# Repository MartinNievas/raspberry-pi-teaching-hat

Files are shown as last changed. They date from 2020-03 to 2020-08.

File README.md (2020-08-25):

# raspberry-pi-teaching-hat

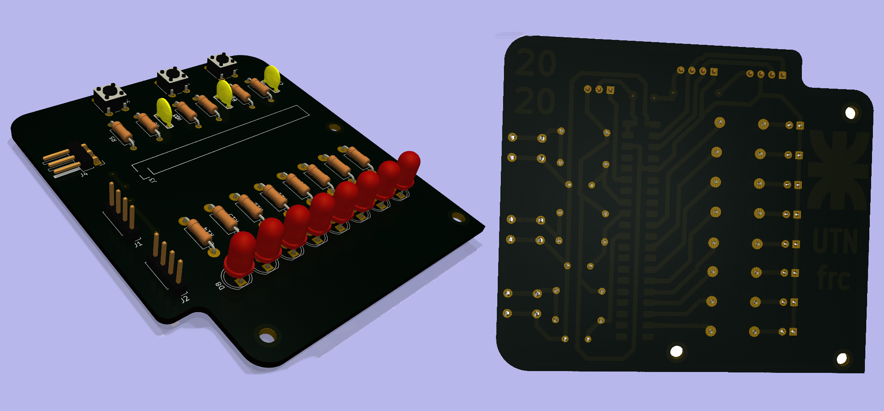
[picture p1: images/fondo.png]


## Pinout

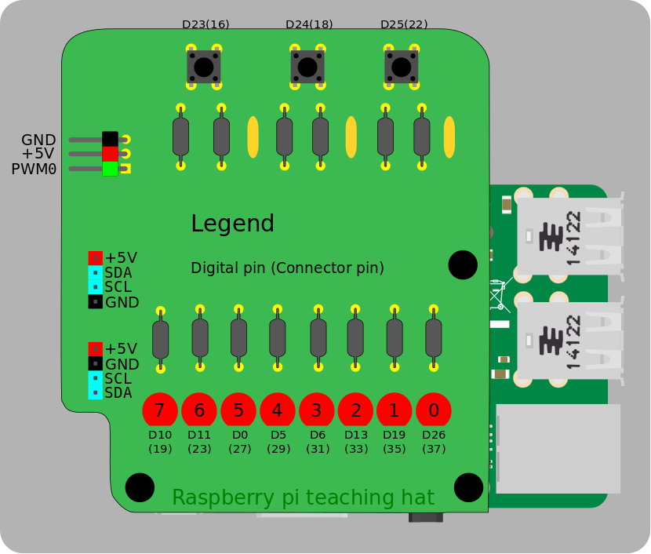
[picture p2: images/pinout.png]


## Programa de ejemplo
Un programa de ejemplo se encuentra en la carpeta lib/

Ejecutar:

```bash
gcc ejemplo.c && sudo ./a.out
```
Nota: sudo es necesario para acceder al pinout.

---
Para más información ir a la [Wiki](https://github.com/MartinNievas/raspberry-pi-teaching-hat/wiki)
---

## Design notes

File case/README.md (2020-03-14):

# Case

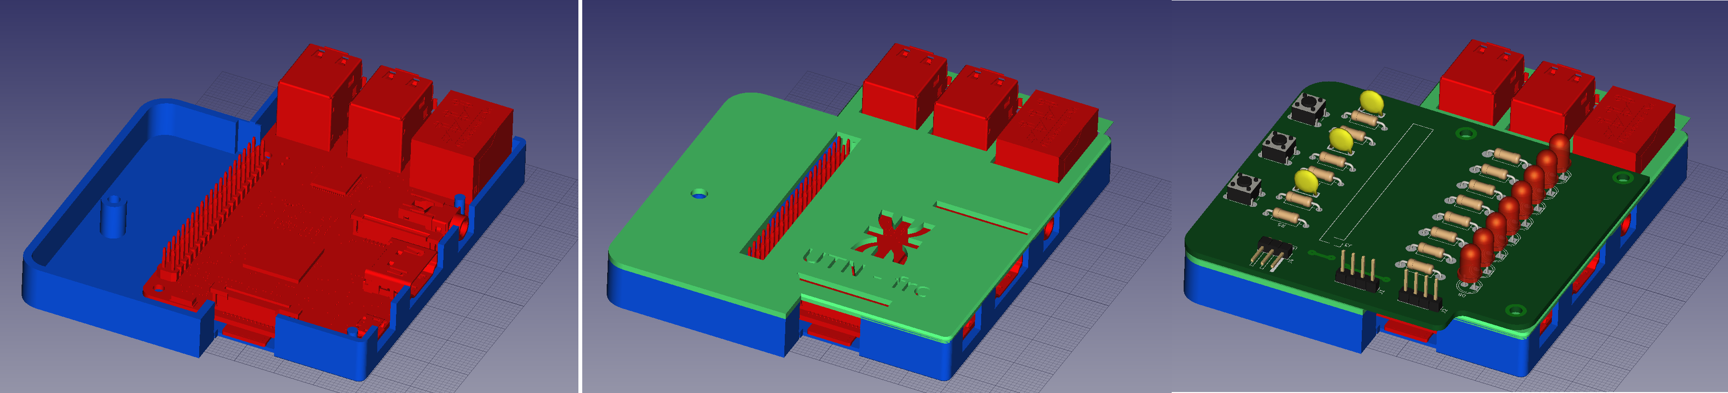
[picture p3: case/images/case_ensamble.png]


En este directorio se encuentra:
- archivos para imprimir en 3D (stl)
- el modelo de FreeCAD (V 0.18.4) para modificar.

### Modelos stl
Los modelos stl para descargar son:
- [base](stl/bottom.stl)
- [tapa](stl/top.stl)

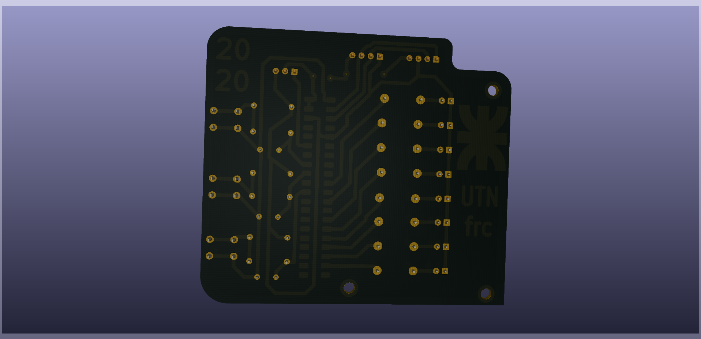
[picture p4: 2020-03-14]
images/atras.png

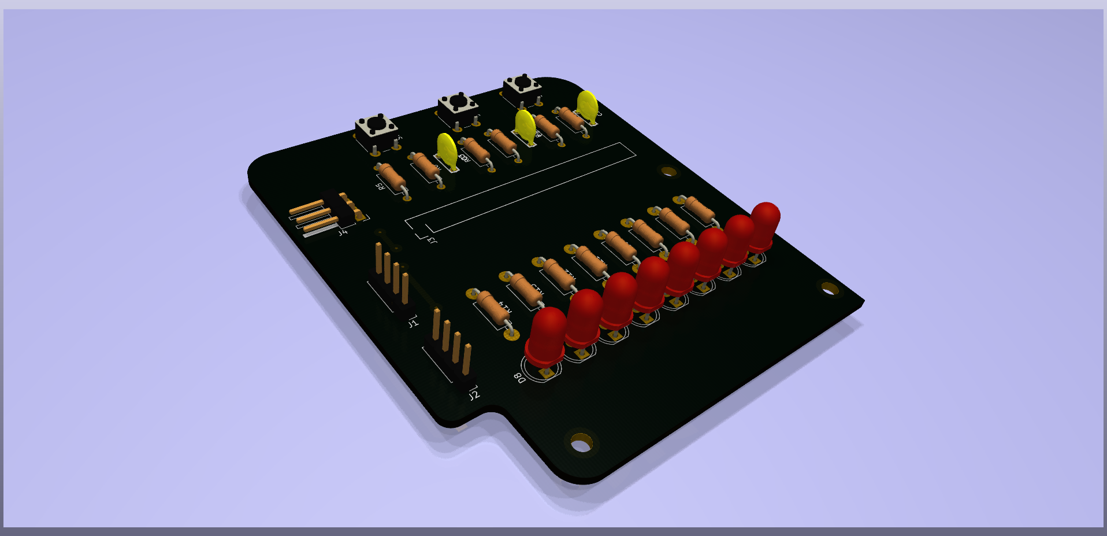
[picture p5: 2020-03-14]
images/adelante.png

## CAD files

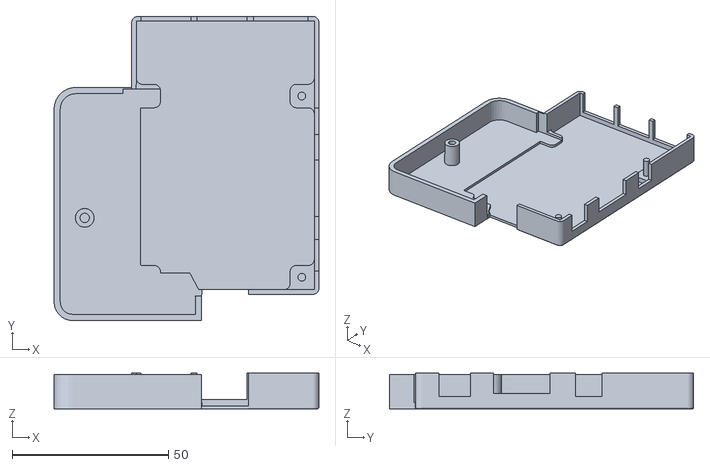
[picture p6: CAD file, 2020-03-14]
case/stl/bottom.stl
84.8 x 97.4 x 11.5

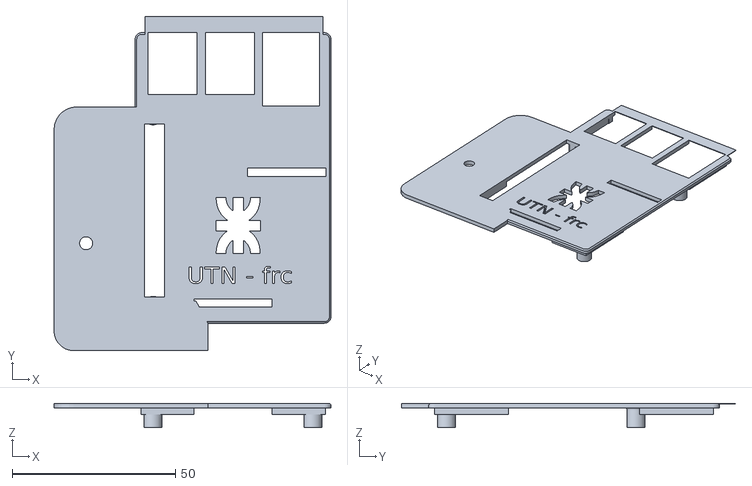
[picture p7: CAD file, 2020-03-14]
case/stl/top.stl
84.8 x 102.4 x 7.50

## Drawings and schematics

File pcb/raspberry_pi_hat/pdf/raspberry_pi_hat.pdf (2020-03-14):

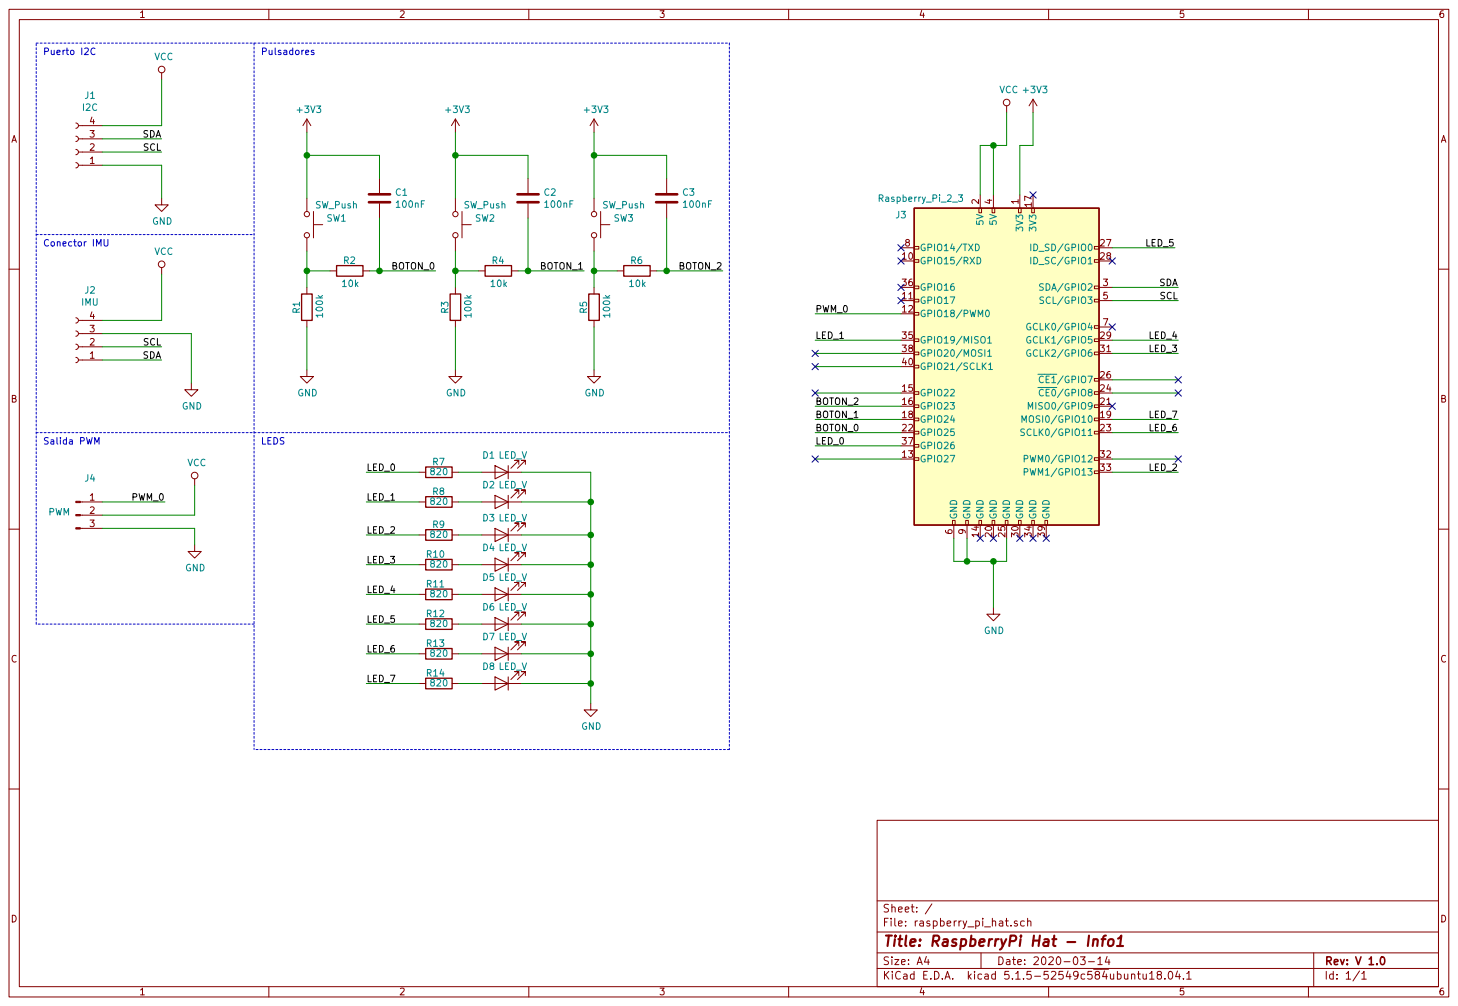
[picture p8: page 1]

Puerto I2C 3 SCL SDA 2 1

Conector IMU VCC 3

Salida PWM 3 | LEDS 820 D1 LED_V

File: raspberry_pi_hat.sch Sheet: /
Id: 1/1 Title: RaspberryPi Hat - Info1

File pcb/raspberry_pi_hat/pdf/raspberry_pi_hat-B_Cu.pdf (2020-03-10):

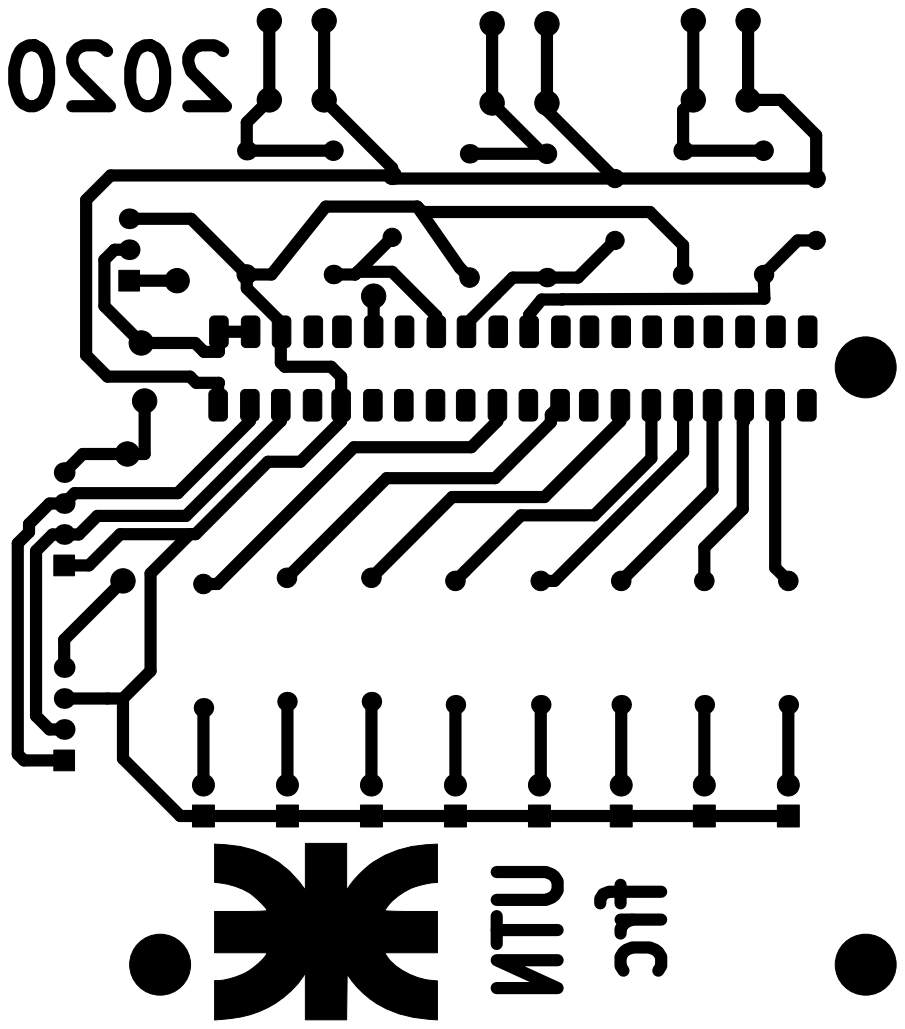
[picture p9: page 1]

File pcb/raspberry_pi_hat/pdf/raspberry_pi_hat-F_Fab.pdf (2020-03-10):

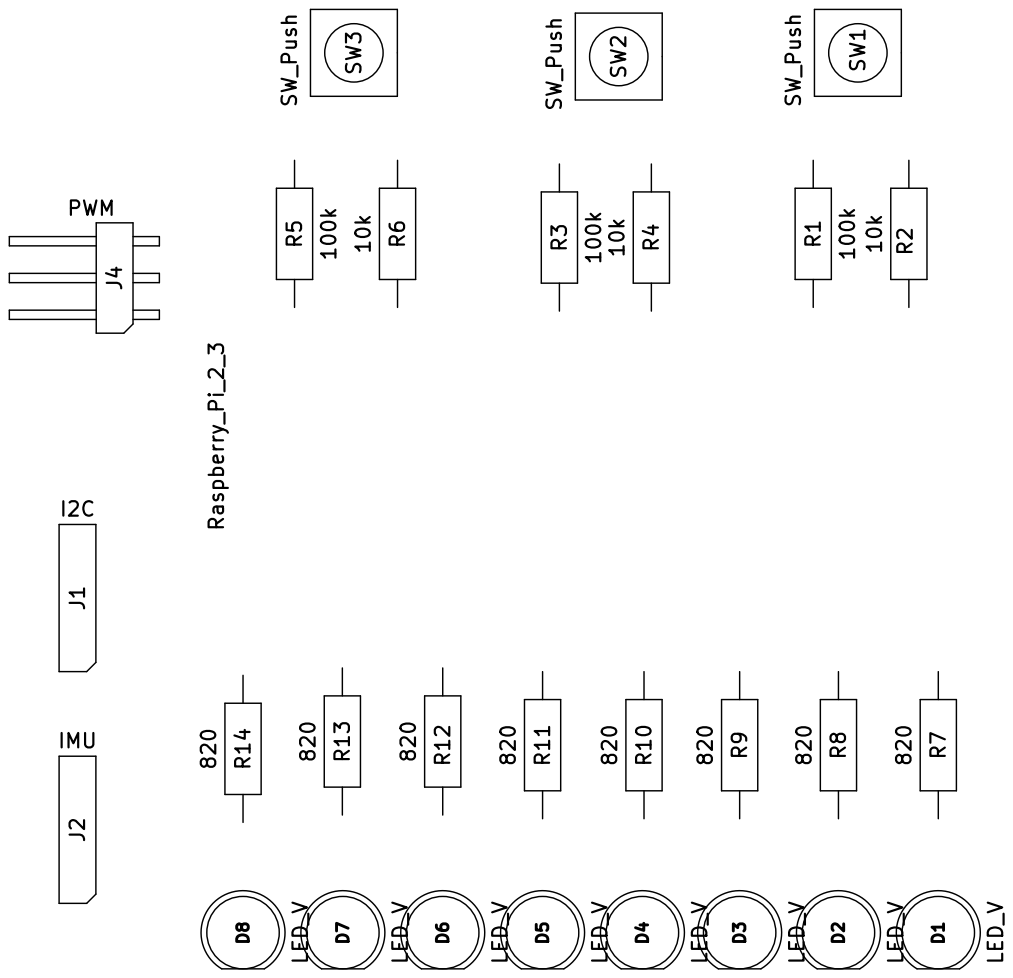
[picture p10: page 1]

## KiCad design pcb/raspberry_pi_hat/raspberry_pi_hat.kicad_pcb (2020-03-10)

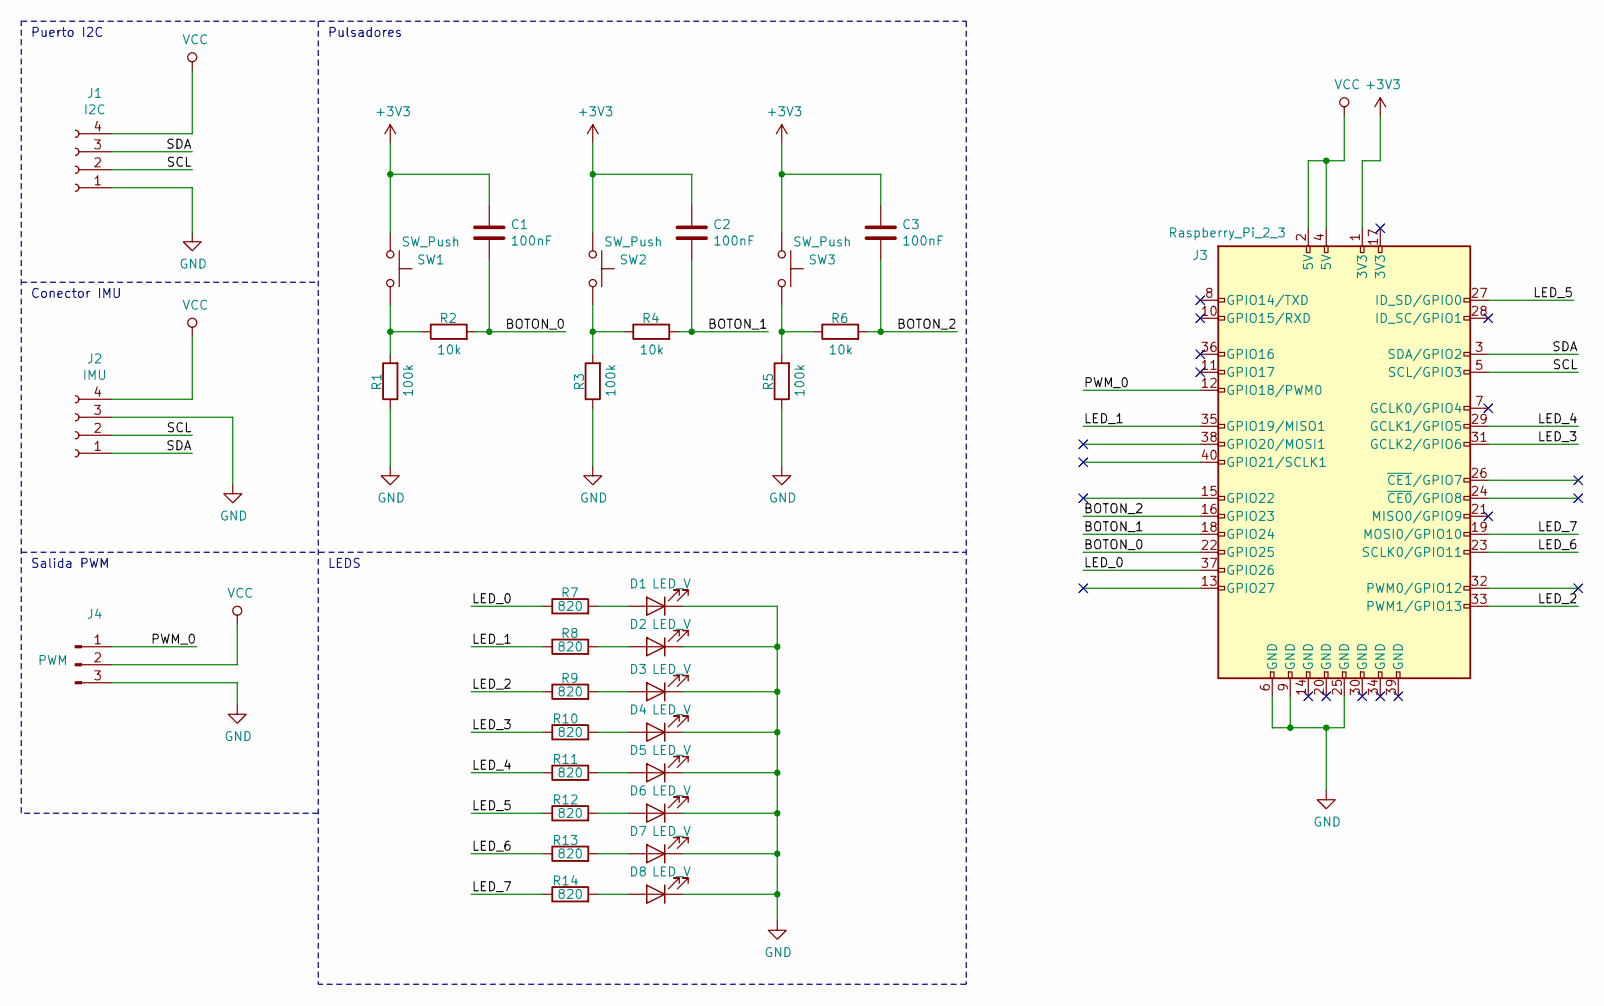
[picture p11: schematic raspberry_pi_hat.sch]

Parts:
C1, C2, C3: 100nF; cnp_6mm_disc
D1, D2, D3, D4, D5, D6, D7, D8: LED_V; LED_D5.0mm
J1: I2C; PinHeader_1x04_P2.54mm_Vertical
J2: IMU; PinHeader_1x04_P2.54mm_Vertical
J3: Raspberry_Pi_2_3; Pin_Header_Straight_2x20
J4: PWM; PinHeader_1x03_P2.54mm_Horizontal
R1, R3, R5: 100k; R_BIG_Axial_DIN0207
R2, R4, R6: 10k; R_BIG_Axial_DIN0207
R7, R8, R9, R10, R11, R12, R13, R14: 820; R_BIG_Axial_DIN0207
SW1, SW2, SW3: SW_Push; SW_PUSH_6mm

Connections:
+3V3: C1.1, C2.1, C3.1, J3.1 (3V3), SW1.1, SW2.1, SW3.1
/BOTON_0: C1.2, J3.22 (GPIO25), R2.2
/BOTON_1: C2.2, J3.18 (GPIO24), R4.2
/BOTON_2: C3.2, J3.16 (GPIO23), R6.2
/LED_0: J3.37 (GPIO26), R7.1
/LED_1: J3.35 (GPIO19/MISO1), R8.1
/LED_2: J3.33 (PWM1/GPIO13), R9.1
/LED_3: J3.31 (GCLK2/GPIO6), R10.1
/LED_4: J3.29 (GCLK1/GPIO5), R11.1
/LED_5: J3.27 (ID_SD/GPIO0), R12.1
/LED_6: J3.23 (SCLK0/GPIO11), R13.1
/LED_7: J3.19 (MOSI0/GPIO10), R14.1
/PWM_0: J3.12 (GPIO18/PWM0), J4.1
/SCL: J1.2, J2.2, J3.5 (SCL/GPIO3)
/SDA: J1.3, J2.1, J3.3 (SDA/GPIO2)
GND: D1.1 (K), D2.1 (K), D3.1 (K), D4.1 (K), D5.1 (K), D6.1 (K), D7.1 (K), D8.1 (K), J1.1, J2.3, J3.6 (GND), J3.9 (GND), J3.25 (GND), J4.3, R1.1, R3.1, R5.1
unnamed: D1.2 (A), R7.2
unnamed: D2.2 (A), R8.2
unnamed: D3.2 (A), R9.2
unnamed: D4.2 (A), R10.2
unnamed: D5.2 (A), R11.2
unnamed: D6.2 (A), R12.2
unnamed: D7.2 (A), R13.2
unnamed: D8.2 (A), R14.2
unnamed: R1.2, R2.1, SW1.2
unnamed: R3.2, R4.1, SW2.2
unnamed: R5.2, R6.1, SW3.2
VCC: J1.4, J2.4, J3.2 (5V), J3.4 (5V), J4.2

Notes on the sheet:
Puerto I2C
Conector IMU
Salida PWM
LEDS
Pulsadores

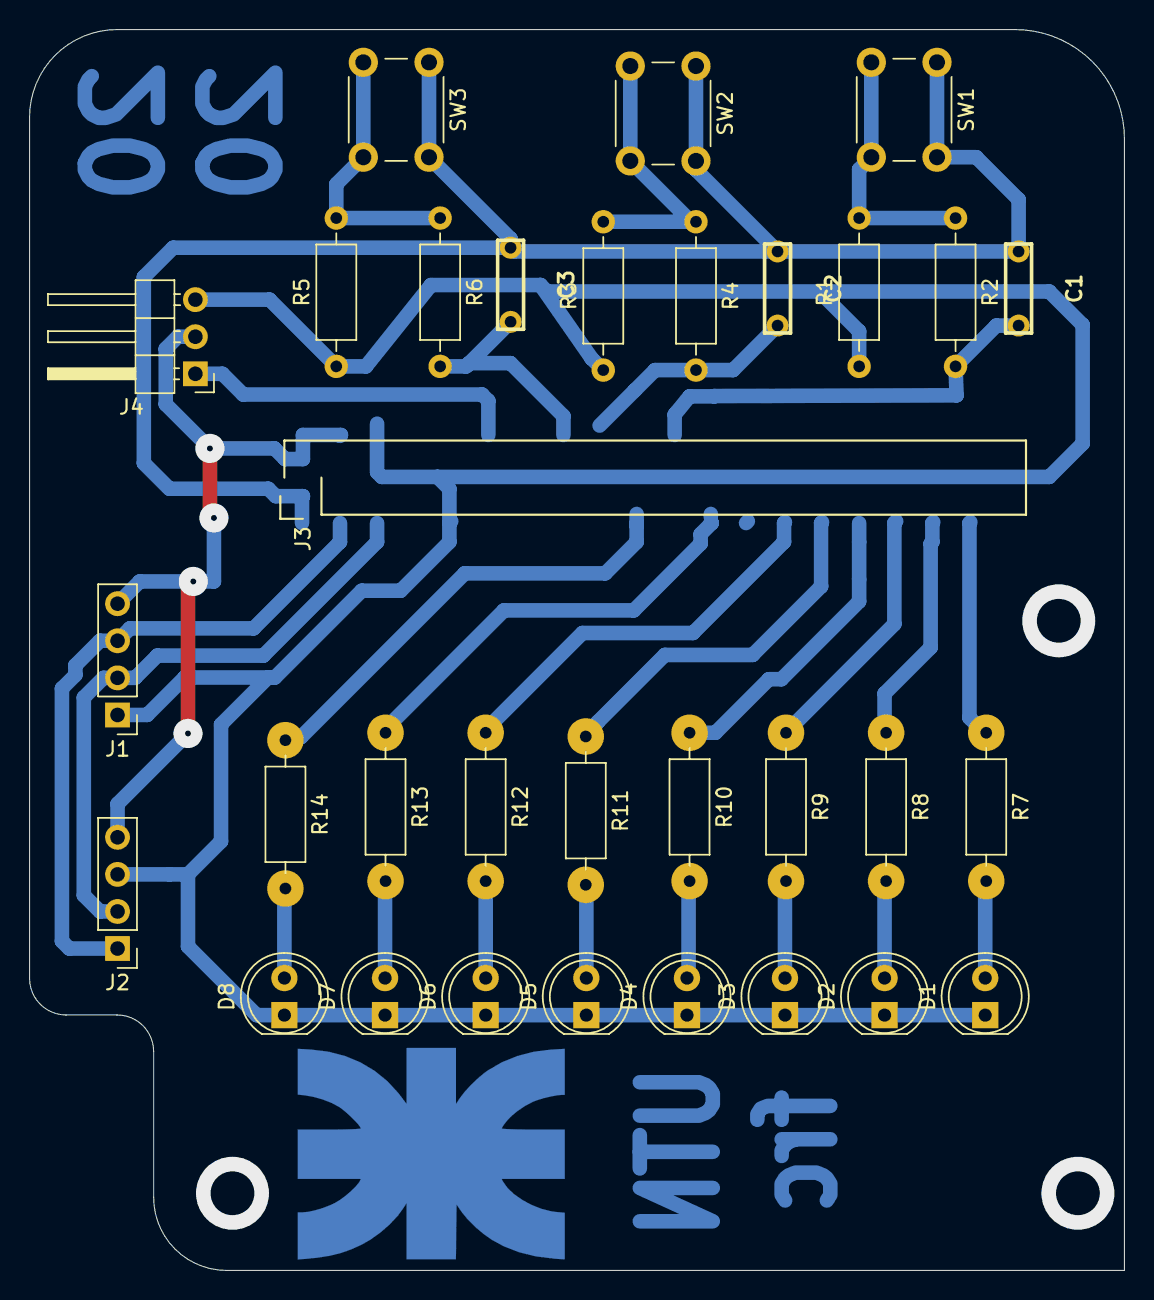
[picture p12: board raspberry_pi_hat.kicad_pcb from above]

Board: 2 copper layers, 75.0 x 85.0 mm, 32 parts (0 on the bottom side), 28 nets.

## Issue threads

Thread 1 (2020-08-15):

Pasar de MAkefile a CMakeFile

MartinNievas, 2020-08-15:
La idea es lo del título. En la carpeta /lib está el archivo, se podría renombrar /lib a /code y crear los ejemplos dentro. Lo dejo abierto para que alguien pueda tomarlo

- [ ] Renombrar la carpeta /lib a /code
- [ ] Crear el archivo CMakeLists.txt con las dependencias necesarias para compilar el código y biblioteca
- [ ] Mover el código a /code/src y las bibliotecas estáticas a /code/lib

MartinNievas, 2020-08-25:
Cuando se renombren los directorios, hay que actualizar la wiki también

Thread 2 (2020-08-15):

Migrar la documentación a la wiki del repo

MartinNievas, 2020-08-15:
La documentación de la placa actual, originalmente estaba en el [blog](https://martinnievas.com/myblog/2020-03-15-raspberrypi-teaching-hat/).
La [versión anterior](https://martinnievas.com/myblog/2019-10-09-placa-raspberry-pi/) (que eran un montón de fotos) quedará por cuestiones históricas, pero habría que mencionarla en la wiki para tener una referencia de porqué se usaron esos piners.

MartinNievas, 2020-08-25:
Migrada!
Faltaría gente para no transformar esto en un largo y aburrido monólogo (*pst* vos que estás leyendo esto, los PR son bienvenidos)

MartinNievas, 2020-08-25:
[La wiki](https://github.com/MartinNievas/raspberry-pi-teaching-hat/wiki) is Up!

Closed 2020-10-14.

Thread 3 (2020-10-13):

Agregar sugerencia de correr con sudo cuando no se puede abrir el archivo

MartinNievas, 2020-10-13:
El programa debe ser ejecutado con `sudo` para poder acceder a `/dev/mem`, de lo contrario muestra un error:

```bash
can't open /dev/mem
```
Que puede no llegar a ser claro su origen

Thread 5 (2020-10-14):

Faltan los links al esquemático en la wiki

MartinNievas, 2020-10-14:
El [link](https://github.com/MartinNievas/raspberry-pi-teaching-hat/blob/master/pcb/raspberry_pi_hat/pdf/raspberry_pi_hat.pdf)  al esquemático no está en la wiki, podría ser de utilidad.

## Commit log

2019-07-02 Add gitignore for KiCad files
2020-02-26 Agrega versión 0.1 del hat
    [raspberry_pi_hat.kicad_pcb, raspberry_pi_hat.sch]
2020-02-26 Agrega renders de la placa
2020-03-10 Agrega modificaciones en el tamaño del PCB
    [raspberry_pi_hat.kicad_pcb, raspberry_pi_hat.sch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]
2020-03-14 Agrega modelos para el case
    [bottom.stl, top.stl]
2020-03-14 Agrega render de la placa
    [raspberry_pi_hat.sch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]
2020-03-14 Agrega links a los modelos stl
2020-03-14 Agrega imágenes de la placa nueva
2020-03-14 Corrige una esquina del case
2020-03-19 Agrega biblioteca EasyPIO.h y programa de ejemplo
2020-03-22 Agrega Makefile y ejemplo de la imu
    - Se agrega un makefile para compilar los programas de ejemplo
    - Se agrega un ejemplo para utilizar la IMU MPU6050 conectada a la placa
2020-03-28 Agrega aplicación de ejemplo para manejar PWM
    - Aplicación utilizando la biblioteca EasyPIO
    - Aplicación utilizando la wiringPi
2020-08-25 Agrega link a la wiki
2021-05-02 Agrega recordatorio de utilizar sudo
